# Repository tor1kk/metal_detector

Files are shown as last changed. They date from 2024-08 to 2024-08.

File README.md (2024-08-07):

# STM32 Based VLF Metal Detector Experiment(Ongoing)

## Introduction
The goal of this project is to develop a custom board with an STM32 microcontroller and utilize an existing commercial search coil. The working principle is as follows: a sinusoidal signal of a specific frequency is generated on the transmitting coil. The search coil is balanced so that in the absence of metal under it, the amplitude of the sinusoid on the receiving coil is minimal. If metal appears under the coil, the amplitude of the sinusoid on the receiving coil increases. The closer the metal or the larger the metal, the greater the amplitude. Additionally, it is possible to differentiate between metals by calculating the phase shift of the sinusoid on the receiving coil relative to the transmitting coil. This requires simultaneous reading of signals from both the transmitting and receiving coils, achieved using ADC dual regular simultaneous mode.

The information about the phase shift and the power of the received signal is displayed on the screen. In this project, LVGL was used to create the graphical interface.

## Project Overview
### Goals
The primary objective is to create a functioning metal detector using an STM32 microcontroller, with the capability to display signal data on a screen using LVGL. 

### Challenges
During the project, significant difficulties were encountered. When connecting the coil, the transmitted signal became distorted. This is likely due to an improperly designed matching circuit, although the exact cause was not determined. Any suggestions or ideas are welcome.

### Hardware
- **Microcontroller**: STM32H723ZGT6 was used to ensure sufficient processing power for rapid calculations. ADC1 and ADC2 were used in dual regular simultaneous mode to acquire signals from the coils. DAC was used to generate the signal for the coil and another DAC channel for sound generation.
- **Display**: A 2.8 inch display with an ILI9341 controller with a resistive touch screen on XPT2046 was used.
- **Schematic**: The schematic can be viewed in the `Hardware` folder in PDF format. [View Schematic](hardware/metal_detector_prototype.pdf)

### Software
- **Code**: The code related to this project is located in the `Program` folder.
- **Documentation**: The code is commented, and Doxygen documentation was generated. [View Doxygen Documentation](https://tor1kk.github.io/metal_detector/software/Program/Doc/html/index.html)

## Test Videos
### Working Test
A video demonstration of the working test can be found below: [View Test Video](media/test.mp4)

### Signal Distortion
A video showing the signal distortion when the coil is connected can be found below:[View Signal Distortion Video](media/signal_distortion.mp4)

## Images
### PCB Photo
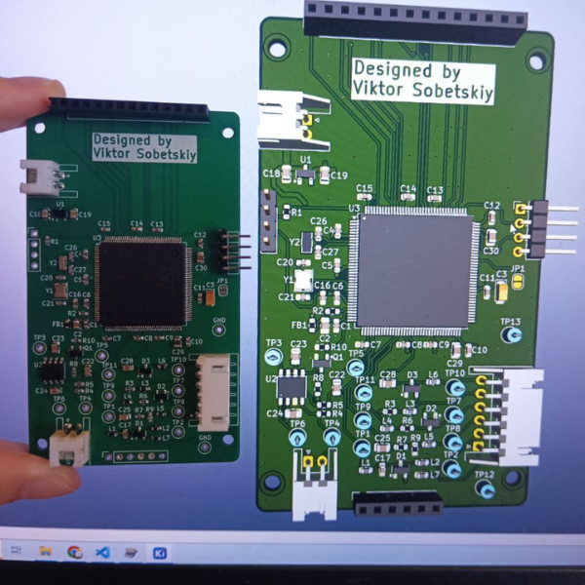
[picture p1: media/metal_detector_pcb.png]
PCB Photo


## Conclusion
This project has been a valuable learning experience, despite the challenges faced. Further work is required to resolve the signal distortion issue and improve the overall performance of the metal detector.

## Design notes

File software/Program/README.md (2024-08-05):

# Project Structure

## **Program** folder contains:

### **Display**
Contains code related to the display:
- **Inc**
    - `display.h` - Header file for display initialization and LVGL integration.
    - `ili9341.h` - Header file for the ili9341 driver.
    - `xpt2046.h` - Header file for the xpt2046 driver.
- **Src**
    - `display.c` - Implementation of display initialization and LVGL integration.
    - `ili9341.c` - Implementation of the ili9341 driver.
    - `xpt2046.c` - Implementation of the xpt2046 driver.

### **SignalsProcessing**
Contains code related to signal processing:
- **Inc**
    - `app_signal.h` - Header file for managing data acquired from ADC and signal generation through DAC, as well as digital signal processing algorithms like FFT.
    - `metal_detecting.h` - Header file for the metal detection algorithm.
- **Src**
    - `app_signal.c` - Implementation of managing data acquired from ADC and signal generation through DAC, as well as digital signal processing algorithms like FFT.
    - `metal_detecting.c` - Implementation of the metal detection algorithm.

### **Tasks**
Implementation of FreeRTOS tasks:
- **Inc**
    - `app_tasks.h` - Header file for tasks.
- **Src**
    - `app_tasks.c` - Implementation of tasks.

### **UI**
Modified user interface code utilizing LVGL generated by SquareLine:
- **Inc**
    - `ui.h` - Header file for user interface objects.
    - `ui_callbacks.h` - Header file for callbacks.
- **Src**
    - `ui.c` - Implementation of user interface objects.
    - `ui_callbacks.c` - Implementation of callbacks.

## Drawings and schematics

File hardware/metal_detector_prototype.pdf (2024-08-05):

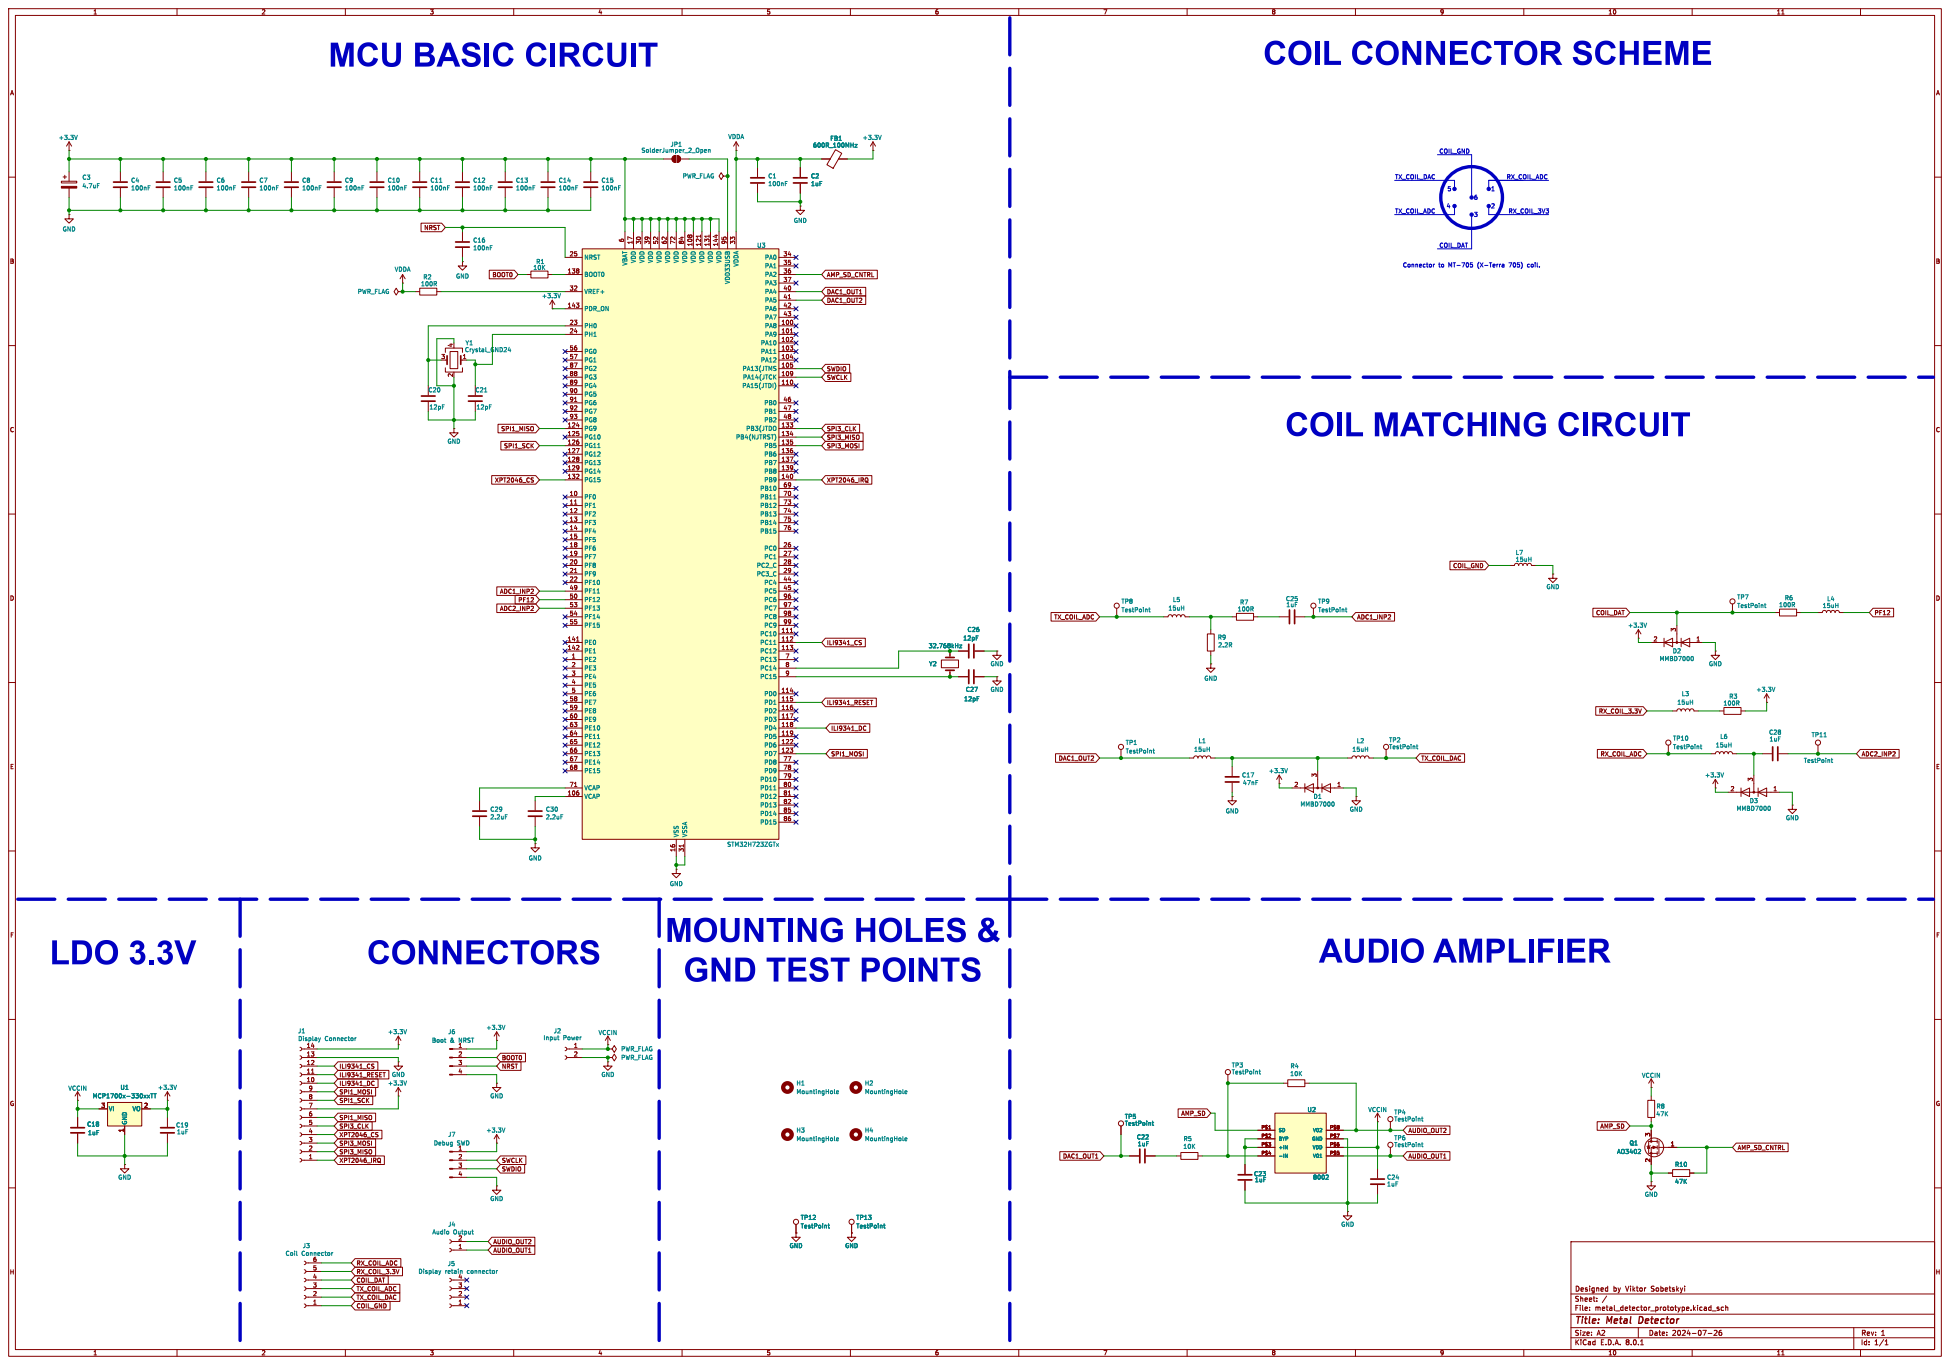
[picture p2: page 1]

1 VO 2 VI 3 GND GND

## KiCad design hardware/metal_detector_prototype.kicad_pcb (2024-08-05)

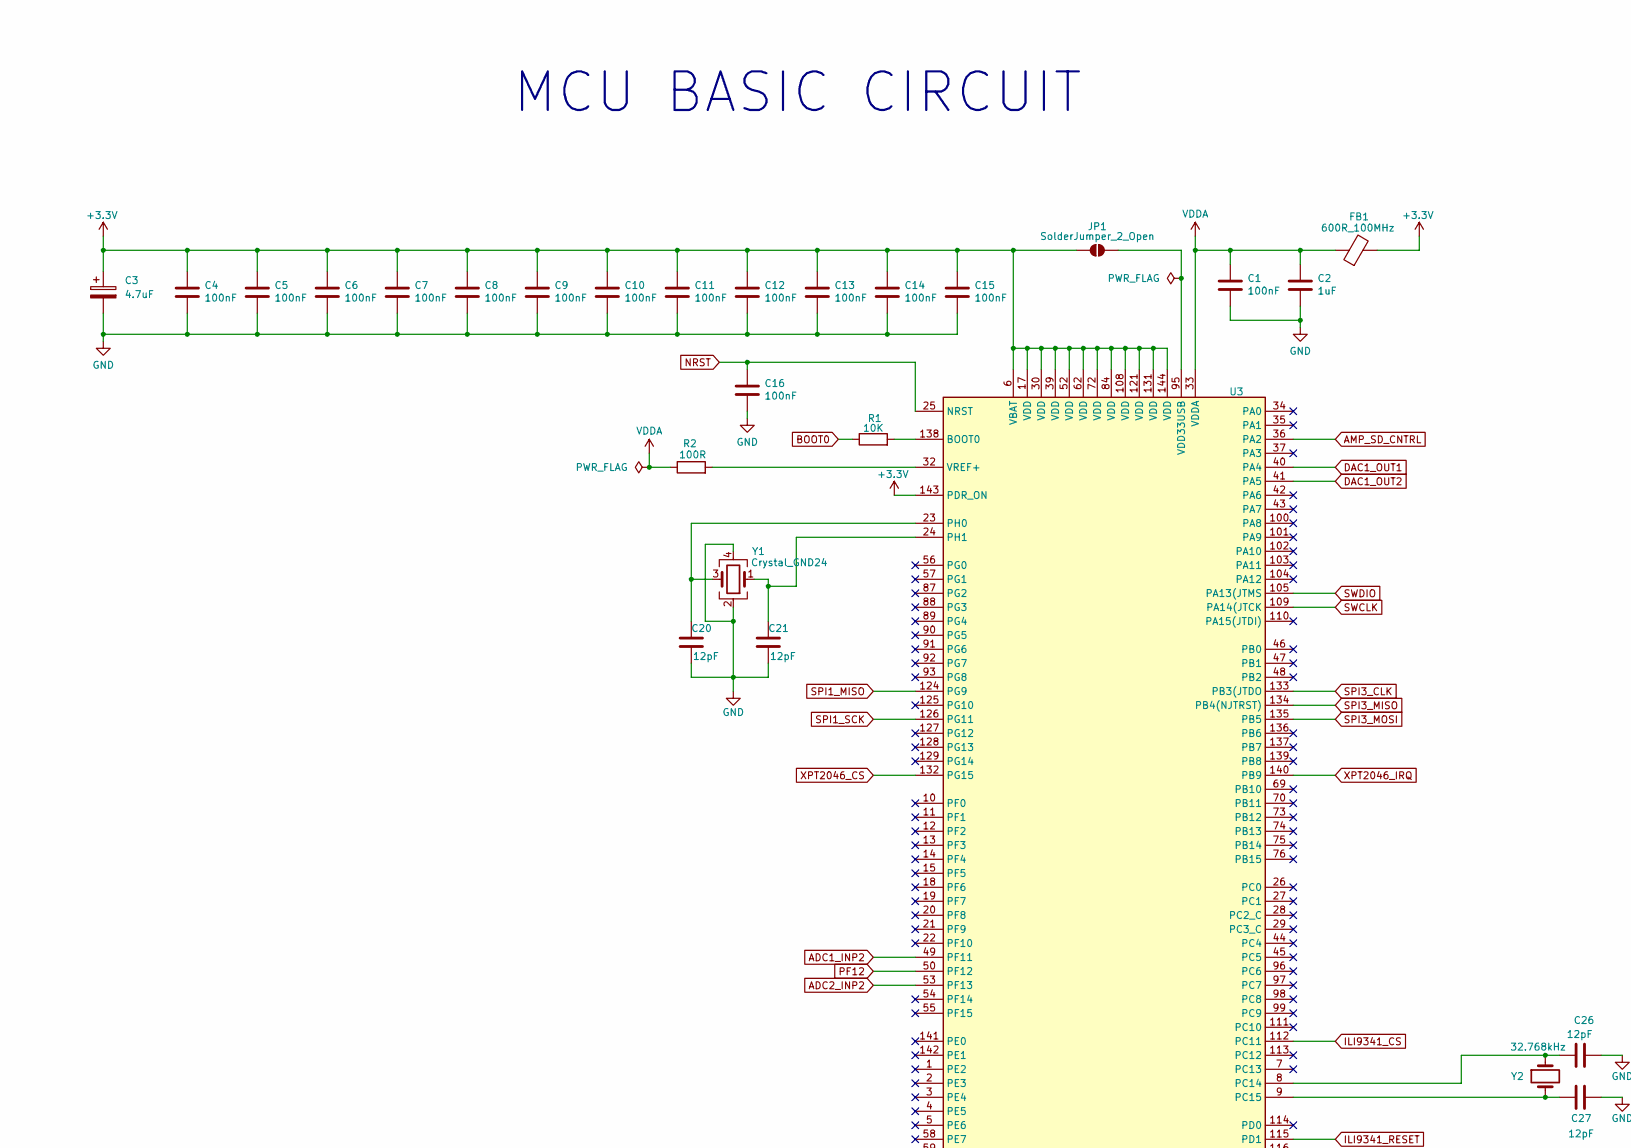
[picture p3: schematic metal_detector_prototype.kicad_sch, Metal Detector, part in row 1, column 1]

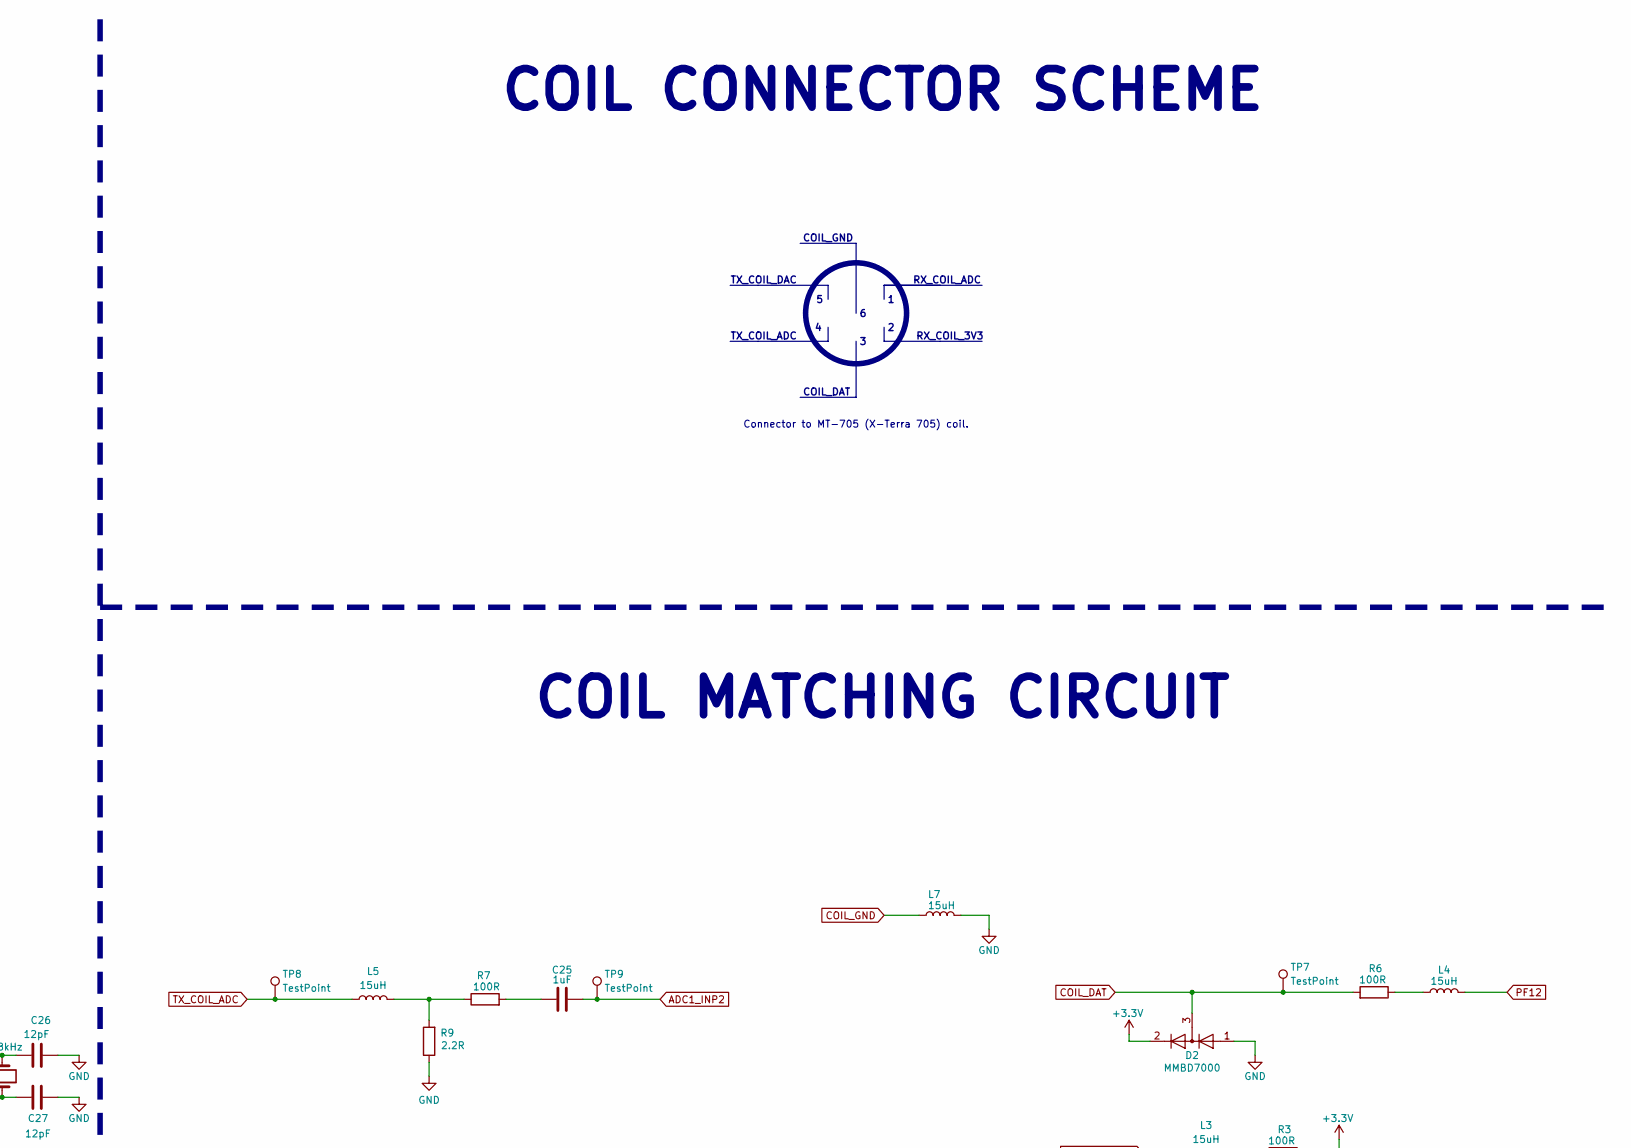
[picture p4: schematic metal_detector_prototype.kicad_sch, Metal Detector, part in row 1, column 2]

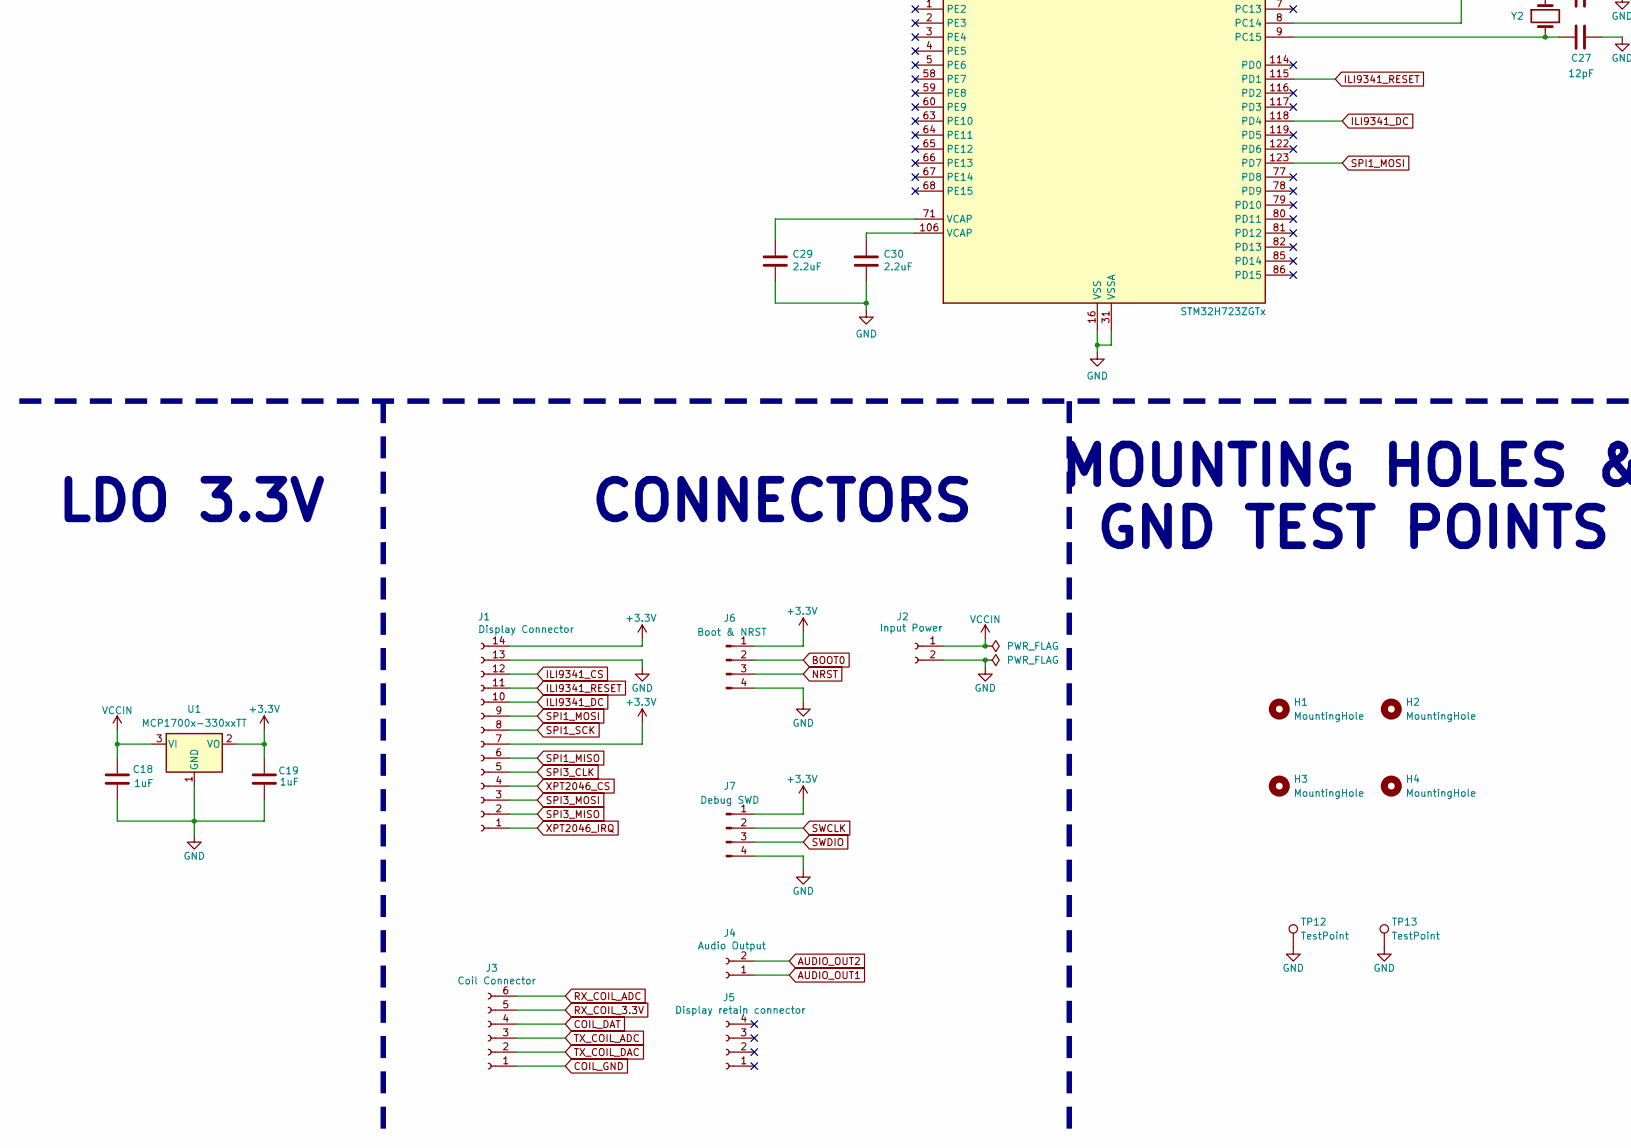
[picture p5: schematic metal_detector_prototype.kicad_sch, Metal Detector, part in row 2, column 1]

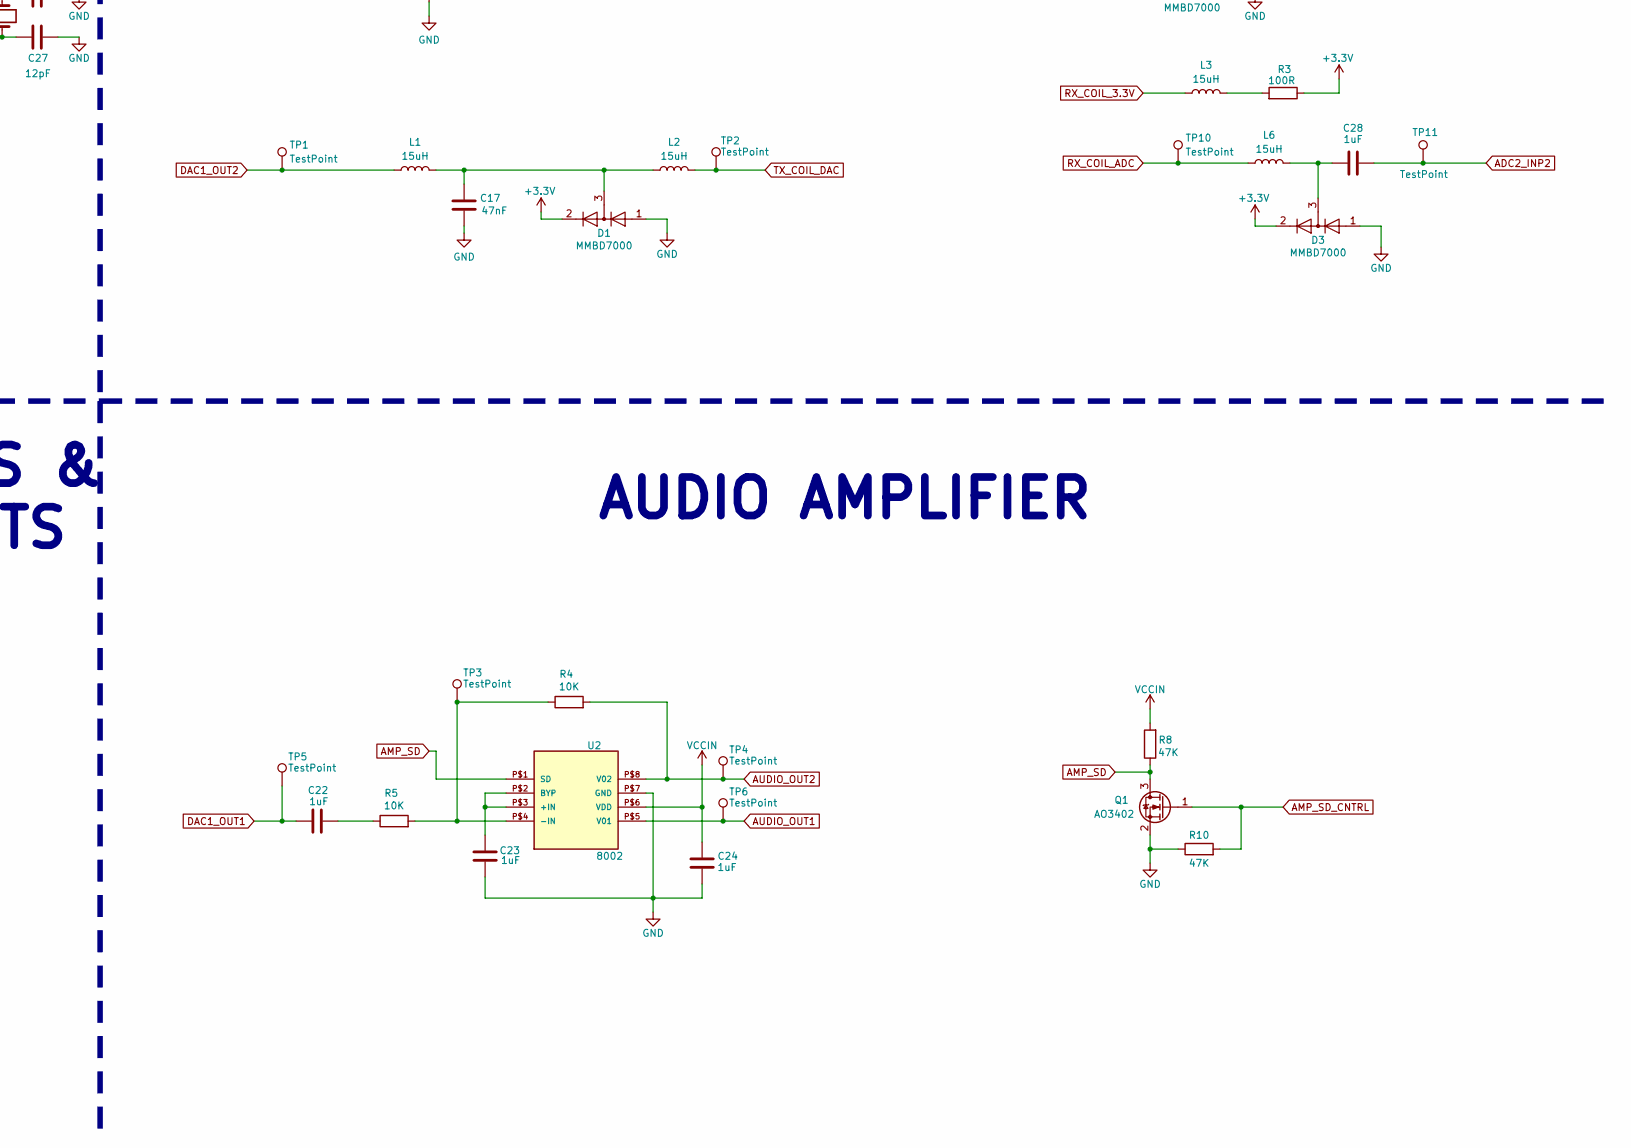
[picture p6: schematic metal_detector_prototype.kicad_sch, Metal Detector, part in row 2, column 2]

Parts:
C1, C4, C5, C6, C7, C8, C9, C10, C11, C12, C13, C14, C15, C16: 100nF; C_0603_1608Metric
C2, C18, C19, C22, C23, C24, C25, C28: 1uF; C_0805_2012Metric
C3: 4.7uF; CP_EIA-3216-18_Kemet-A
C17: 47nF; C_0603_1608Metric
C20, C21, C26, C27: 12pF; C_0603_1608Metric
C29, C30: 2.2uF; C_0805_2012Metric
D1, D2, D3: MMBD7000; SOT-23
FB1: 600R_100MHz; R_0603_1608Metric
H1, H2, H3, H4: MountingHole; MountingHole_2.7mm_M2.5_ISO7380
J1: Display Connector; PinSocket_1x14_P2.54mm_Vertical
J2: Input Power; JST_XH_S2B-XH-A-1_1x02_P2.50mm_Horizontal
J3: Coil Connector; JST_XH_S6B-XH-A_1x06_P2.50mm_Horizontal
J4: Audio Output; JST_XH_S2B-XH-A_1x02_P2.50mm_Horizontal
J5: Display retain connector; PinSocket_1x06_P2.54mm_Vertical
J6: Boot & NRST; PinHeader_1x04_P2.54mm_Vertical
J7: Debug SWD; PinHeader_1x04_P2.54mm_Horizontal
JP1: SolderJumper_2_Open; SolderJumper-2_P1.3mm_Open_RoundedPad1.0x1.5mm
L1, L2, L3, L4, L5, L6, L7: 15uH; L_0603_1608Metric
Q1: AO3402; SOT-23
R1, R4, R5: 10K; R_0603_1608Metric
R2, R3, R6, R7: 100R; R_0603_1608Metric
R8, R10: 47K; R_0603_1608Metric
R9: 2.2R; R_0603_1608Metric
TP1, TP2, TP3, TP4, TP5, TP6, TP7, TP8, TP9, TP10, TP11, TP12, TP13: TestPoint; TestPoint_Loop_D1.80mm_Drill1.0mm_Beaded
U1: MCP1700x-330xxTT; SOT-23
U2: 8002; SOIC8
U3: STM32H723ZGTx; LQFP-144_20x20mm_P0.5mm
Y1: Crystal_GND24; Crystal_SMD_3225-4Pin_3.2x2.5mm
Y2: 32.768kHz; Crystal_SMD_3215-2Pin_3.2x1.5mm

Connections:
+3.3V: C3.1, C4.1, C5.1, C6.1, C7.1, C8.1, C9.1, C10.1, C11.1, C12.1, C13.1, C14.1, C15.1, C19.2, D1.2 (A), D2.2 (A), D3.2 (A), FB1.2, J1.7, J1.14, J6.1, J7.1, JP1.1 (A), R3.1, U1.2 (VO), U3.6 (VBAT), U3.17 (VDD), U3.30 (VDD), U3.39 (VDD), U3.52 (VDD), U3.62 (VDD), U3.72 (VDD), U3.84 (VDD), U3.108 (VDD), U3.121 (VDD), U3.131 (VDD), U3.143 (PDR_ON), U3.144 (VDD)
ADC1_INP2: C25.2, TP9.1, U3.49 (PF11)
ADC2_INP2: C28.2, TP11.1, U3.53 (PF13)
AMP_SD: Q1.3 (D), R8.1, U2.P$1 (SD)
AMP_SD_CNTRL: Q1.1 (G), R10.2, U3.36 (PA2)
AUDIO_OUT1: J4.1, TP6.1, U2.P$5 (V01)
AUDIO_OUT2: J4.2, R4.2, TP4.1, U2.P$8 (V02)
BOOT0: J6.2, R1.1
COIL_DAT: D2.3 (K), J3.4, R6.2, TP7.1
COIL_GND: J3.1, L7.1
DAC1_OUT1: C22.2, TP5.1, U3.40 (PA4)
DAC1_OUT2: L1.1, TP1.1, U3.41 (PA5)
GND: C1.2, C2.2, C3.2, C4.2, C5.2, C6.2, C7.2, C8.2, C9.2, C10.2, C11.2, C12.2, C13.2, C14.2, C15.2, C16.2, C17.2, C18.1, C19.1, C20.1, C21.1, C23.2, C24.1, C26.1, C27.1, C29.2, C30.2, D1.1 (K), D2.1 (K), D3.1 (K), J1.13, J2.2, J6.4, J7.4, L7.2, Q1.2 (S), R9.1, R10.1, TP12.1, TP13.1, U1.1 (GND), U2.P$7 (GND), U3.16 (VSS), U3.31 (VSSA), U3.38 (VSS), U3.51 (VSS), U3.61 (VSS), U3.83 (VSS), U3.94 (VSS), U3.107 (VSS), U3.120 (VSS), U3.130 (VSS), Y1.2, Y1.4
ILI9341_CS: J1.12, U3.112 (PC11)
ILI9341_DC: J1.10, U3.118 (PD4)
ILI9341_RESET: J1.11, U3.115 (PD1)
NRST: C16.1, J6.3, U3.25 (NRST)
unnamed: C17.1, D1.3 (K), L1.2, L2.1
unnamed: C22.1, R5.1
unnamed: C25.1, R7.2
unnamed: C28.1, D3.3 (K), L6.2
unnamed: C29.1, U3.71 (VCAP)
unnamed: C30.1, U3.106 (VCAP)
unnamed: JP1.2 (B), U3.95 (VDD33USB)
unnamed: L3.1, R3.2
unnamed: L4.2, R6.1
unnamed: L5.2, R7.1, R9.2
unnamed: C23.1, U2.P$2 (BYP), U2.P$3 (+IN)
unnamed: R4.1, R5.2, TP3.1, U2.P$4 (-IN)
unnamed: R1.2, U3.138 (BOOT0)
unnamed: C26.2, U3.8 (PC14), Y2.1
unnamed: C27.2, U3.9 (PC15), Y2.2
unnamed: C20.2, U3.23 (PH0), Y1.3
unnamed: C21.2, U3.24 (PH1), Y1.1
unnamed: R2.2, U3.32 (VREF+)
PF12: L4.1, U3.50 (PF12)
RX_COIL_3.3V: J3.5, L3.2
RX_COIL_ADC: J3.6, L6.1, TP10.1
SPI1_MISO: J1.6, U3.124 (PG9)
SPI1_MOSI: J1.9, U3.123 (PD7)
SPI1_SCK: J1.8, U3.126 (PG11)
SPI3_CLK: J1.5, U3.133 (PB3(JTDO)
SPI3_MISO: J1.2, U3.134 (PB4(NJTRST))
SPI3_MOSI: J1.3, U3.135 (PB5)
SWCLK: J7.2, U3.109 (PA14(JTCK)
SWDIO: J7.3, U3.105 (PA13(JTMS)
TX_COIL_ADC: J3.3, L5.1, TP8.1
TX_COIL_DAC: J3.2, L2.2, TP2.1
VCCIN: C18.2, C24.2, J2.1, R8.2, U1.3 (VI), U2.P$6 (VDD)
VDDA: C1.1, C2.1, FB1.1, R2.1, U3.33 (VDDA)
XPT2046_CS: J1.4, U3.132 (PG15)
XPT2046_IRQ: J1.1, U3.140 (PB9)

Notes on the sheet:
COIL MATCHING CIRCUIT
TX_COIL_DAC
COIL_GND
AUDIO AMPLIFIER
COIL CONNECTOR SCHEME
RX_COIL_3V3
RX_COIL_ADC
COIL_DAT
TX_COIL_ADC
MCU BASIC CIRCUIT
CONNECTORS
Connector to MT-705 (X-Terra 705) coil.
MOUNTING HOLES & GND TEST POINTS
LDO 3.3V

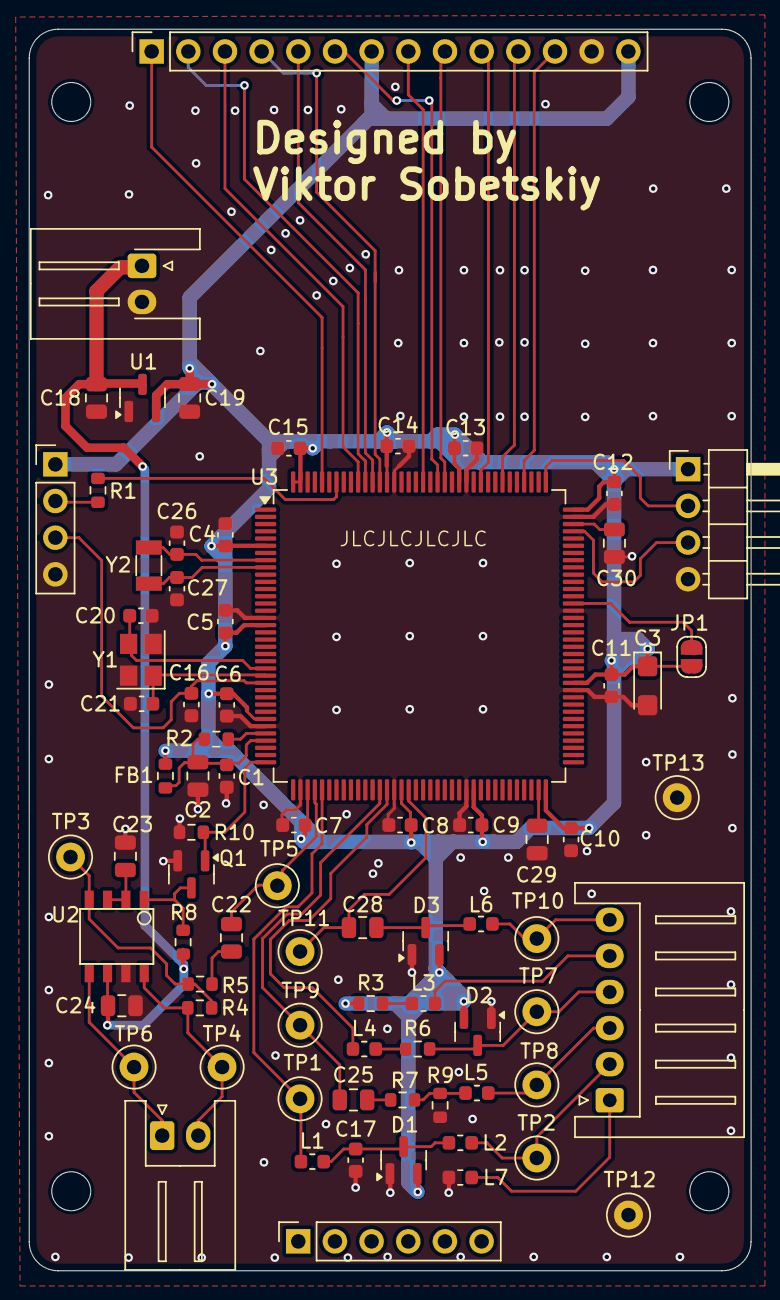
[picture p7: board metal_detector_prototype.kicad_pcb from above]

Board: 4 copper layers, 50.0 x 86.0 mm, 82 parts (0 on the bottom side), 52 nets.

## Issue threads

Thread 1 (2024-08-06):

LP or HP filters

folny, 2024-08-06:
Hi

I'm working on a similar project with STM32H7 and I want to ask if you don't use any LP or HP filters in the project because I couldn't find them anywhere in the code.

tor1kk, 2024-08-06:
Hi,

Thank you very much for your question. No, I did not use digital filters, I think that since I use the information about the magnitude and phase from the exact frequency (at which the signal is generated, and which should also have the largest magnitude), then it makes no sense to filter other frequencies, because they would not were supposed to distort information.

folny, 2024-08-06:
OK, now I understand and how do you calibrate ? I didn't even see a ferrite setting that calibrates the detector to -90 degrees.

tor1kk, 2024-08-06:
Actually, I am not very experienced in this topic. I tried using a commercial coil from the X-Terra 705 metal detector.

The idea was to generate a sine wave at the frequency at which the coil operates and then read the signals from the receiving and transmitting coils. However, I encountered significant issues at this stage.

The transmitting signal is significantly distorted when the coil is connected (as you can see in the video (and yes, I don't have an oscilloscope) ). This is probably because I simply copied the matching circuit from a commercial metal detector, which used an audio codec. Therefore, my setup likely requires a different circuit design.

There is very little information on metal detectors available online, so I don't fully understand the calibration process you mentioned. If you could provide a brief description, I would be grateful, as it might help solve my problem.

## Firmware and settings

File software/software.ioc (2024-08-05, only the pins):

Mcu.UserName=STM32H723ZGTx
PA13(JTMS/SWDIO).Signal=DEBUG_JTMS-SWDIO
PA14(JTCK/SWCLK).Signal=DEBUG_JTCK-SWCLK
PA2.GPIO_Label=AMP_SD_CNTRL
PA2.Signal=GPIO_Output
PA4.Signal=COMP_DAC11_group
PA5.Signal=COMP_DAC12_group
PB3(JTDO/TRACESWO).Signal=SPI3_SCK
PB4(NJTRST).Signal=SPI3_MISO
PB5.Signal=SPI3_MOSI
PB9.GPIO_Label=XPT2046_IRQ
PB9.Signal=GPIO_Input
PC11.GPIO_Label=ILI9341_CS
PC11.Signal=GPIO_Output
PC14-OSC32_IN.Signal=RCC_OSC32_IN
PC15-OSC32_OUT.Signal=RCC_OSC32_OUT
PD1.GPIO_Label=ILI9341_RESET
PD1.Signal=GPIO_Output
PD4.GPIO_Label=ILI9341_DC
PD4.Signal=GPIO_Output
PD7.Signal=SPI1_MOSI
PF11.Signal=ADC1_INP2
PF12.GPIO_Label=COIL_DAT
PF12.Signal=GPIO_Output
PF13.Signal=ADC2_INP2
PG11.Signal=SPI1_SCK
PG15.GPIO_Label=XPT2046_CS
PG15.Signal=GPIO_Output
PG9.Signal=SPI1_MISO
PH0-OSC_IN.Signal=RCC_OSC_IN
PH1-OSC_OUT.Signal=RCC_OSC_OUT

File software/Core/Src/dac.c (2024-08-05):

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
/* Includes ------------------------------------------------------------------*/
#include "dac.h"

DAC_HandleTypeDef hdac1;
DMA_HandleTypeDef hdma_dac1_ch1;
DMA_HandleTypeDef hdma_dac1_ch2;

/* DAC1 init function */
void MX_DAC1_Init(void)
{

  DAC_ChannelConfTypeDef sConfig = {0};

  /** DAC Initialization
  */
  hdac1.Instance = DAC1;
  if (HAL_DAC_Init(&hdac1) != HAL_OK)
  {
    Error_Handler();
  }

  /** DAC channel OUT1 config
  */
  sConfig.DAC_SampleAndHold = DAC_SAMPLEANDHOLD_DISABLE;
  sConfig.DAC_Trigger = DAC_TRIGGER_T2_TRGO;
  sConfig.DAC_OutputBuffer = DAC_OUTPUTBUFFER_ENABLE;
  sConfig.DAC_ConnectOnChipPeripheral = DAC_CHIPCONNECT_DISABLE;
  sConfig.DAC_UserTrimming = DAC_TRIMMING_FACTORY;
  if (HAL_DAC_ConfigChannel(&hdac1, &sConfig, DAC_CHANNEL_1) != HAL_OK)
  {
    Error_Handler();
  }

  /** DAC channel OUT2 config
  */
  if (HAL_DAC_ConfigChannel(&hdac1, &sConfig, DAC_CHANNEL_2) != HAL_OK)
  {
    Error_Handler();
  }
}

void HAL_DAC_MspInit(DAC_HandleTypeDef* dacHandle)
{

  GPIO_InitTypeDef GPIO_InitStruct = {0};
  if(dacHandle->Instance==DAC1)
  {
    /* DAC1 clock enable */
    __HAL_RCC_DAC12_CLK_ENABLE();

    __HAL_RCC_GPIOA_CLK_ENABLE();
    /**DAC1 GPIO Configuration
    PA4     ------> DAC1_OUT1
    PA5     ------> DAC1_OUT2
    */
    GPIO_InitStruct.Pin = GPIO_PIN_4|GPIO_PIN_5;
    GPIO_InitStruct.Mode = GPIO_MODE_ANALOG;
    GPIO_InitStruct.Pull = GPIO_NOPULL;
    HAL_GPIO_Init(GPIOA, &GPIO_InitStruct);

    /* DAC1 DMA Init */
    /* DAC1_CH1 Init */
    hdma_dac1_ch1.Instance = DMA1_Stream0;
    hdma_dac1_ch1.Init.Request = DMA_REQUEST_DAC1;
    hdma_dac1_ch1.Init.Direction = DMA_MEMORY_TO_PERIPH;
    hdma_dac1_ch1.Init.PeriphInc = DMA_PINC_DISABLE;
    hdma_dac1_ch1.Init.MemInc = DMA_MINC_ENABLE;
    hdma_dac1_ch1.Init.PeriphDataAlignment = DMA_PDATAALIGN_WORD;
    hdma_dac1_ch1.Init.MemDataAlignment = DMA_MDATAALIGN_WORD;
    hdma_dac1_ch1.Init.Mode = DMA_CIRCULAR;
    hdma_dac1_ch1.Init.Priority = DMA_PRIORITY_LOW;
    hdma_dac1_ch1.Init.FIFOMode = DMA_FIFOMODE_DISABLE;
    if (HAL_DMA_Init(&hdma_dac1_ch1) != HAL_OK)
    {
      Error_Handler();
    }

    __HAL_LINKDMA(dacHandle,DMA_Handle1,hdma_dac1_ch1);

    /* DAC1_CH2 Init */
    hdma_dac1_ch2.Instance = DMA1_Stream3;
    hdma_dac1_ch2.Init.Request = DMA_REQUEST_DAC2;
    hdma_dac1_ch2.Init.Direction = DMA_MEMORY_TO_PERIPH;
    hdma_dac1_ch2.Init.PeriphInc = DMA_PINC_DISABLE;
    hdma_dac1_ch2.Init.MemInc = DMA_MINC_ENABLE;
    hdma_dac1_ch2.Init.PeriphDataAlignment = DMA_PDATAALIGN_WORD;
    hdma_dac1_ch2.Init.MemDataAlignment = DMA_MDATAALIGN_WORD;
    hdma_dac1_ch2.Init.Mode = DMA_CIRCULAR;
    hdma_dac1_ch2.Init.Priority = DMA_PRIORITY_LOW;
    hdma_dac1_ch2.Init.FIFOMode = DMA_FIFOMODE_DISABLE;
    if (HAL_DMA_Init(&hdma_dac1_ch2) != HAL_OK)
    {
      Error_Handler();
    }

    __HAL_LINKDMA(dacHandle,DMA_Handle2,hdma_dac1_ch2);

  }
}

void HAL_DAC_MspDeInit(DAC_HandleTypeDef* dacHandle)
{

  if(dacHandle->Instance==DAC1)
  {
    /* Peripheral clock disable */
    __HAL_RCC_DAC12_CLK_DISABLE();

    /**DAC1 GPIO Configuration
    PA4     ------> DAC1_OUT1
    PA5     ------> DAC1_OUT2
    */
    HAL_GPIO_DeInit(GPIOA, GPIO_PIN_4|GPIO_PIN_5);

    /* DAC1 DMA DeInit */
    HAL_DMA_DeInit(dacHandle->DMA_Handle1);
    HAL_DMA_DeInit(dacHandle->DMA_Handle2);
  }
}



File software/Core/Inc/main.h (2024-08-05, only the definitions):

#define AMP_SD_CNTRL_Pin GPIO_PIN_2
#define AMP_SD_CNTRL_GPIO_Port GPIOA
#define COIL_DAT_Pin GPIO_PIN_12
#define COIL_DAT_GPIO_Port GPIOF
#define ILI9341_CS_Pin GPIO_PIN_11
#define ILI9341_CS_GPIO_Port GPIOC
#define ILI9341_RESET_Pin GPIO_PIN_1
#define ILI9341_RESET_GPIO_Port GPIOD
#define ILI9341_DC_Pin GPIO_PIN_4
#define ILI9341_DC_GPIO_Port GPIOD
#define XPT2046_CS_Pin GPIO_PIN_15
#define XPT2046_CS_GPIO_Port GPIOG
#define XPT2046_IRQ_Pin GPIO_PIN_9
#define XPT2046_IRQ_GPIO_Port GPIOB

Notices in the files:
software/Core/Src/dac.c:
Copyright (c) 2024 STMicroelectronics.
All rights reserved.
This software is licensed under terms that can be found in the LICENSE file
